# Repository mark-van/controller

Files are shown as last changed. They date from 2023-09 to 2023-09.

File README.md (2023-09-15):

# BLDC Controller

Designed a 300A 70V BLDC controller schematic to conform to relevant safety standards--UL2849, UL2272, and UL2271--and pass EMC certification tests 
- [Schematic PDF](/Project%20Outputs%20for%20Controller/schematics-2023-09-14.pdf) 

<br>

TODO:
- Add remaining safety protection circuits
- Clean up schematic
- Develop thorough documentation that describes the design’s protective circuitry and safety considerations so that it may act as a resource for future projects

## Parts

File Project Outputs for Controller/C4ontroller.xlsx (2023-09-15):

 | Bill of Materials
 |  |  |  |  |  |  | 2175 Salk Avenue
 | Project Title: | Bill of Materials for Project [Controller.PrjPcb] (No PCB Document Selected) |  |  |  |  | Suite 200
 | Project File Name: | Controller.PrjPcb |  |  |  |  | Carlsbad, CA 92008
 | Assembly Variant: | None |  |  |  |  | USA
Part Number | Description | Designator | Manufacture | Manufacture Part Number | Supplier | Supplier Part Number | Supplier Unit Price | Quantity
STM32F446RET6 | RISC Microcontroller, 32-Bit, FLASH, CORTEX-M4F CPU, 180MHz, CMOS, PQFP64 |  |  |  |  |  |  | 1
CGA3E1X7R1C105K080AC | CER 1UF 16V X7R 0603 | C1, C?, C?_U_Half_Bridge_1, C?_U_Half_Bridge_2, C?_U_Half_Bridge_3 |  |  |  |  |  | 14
GCM188R72A103KA37D | CER 10000PF 100V X7R 0603 | C2, C? |  |  |  |  |  | 4
GRT188C81E225KE13D | CER 2.2UF 25V X6S 0603 | C3, C4, C15 |  |  |  |  |  | 3
CGA3E2X7R1H104K080AA | CER 0.1UF 50V X7R 0603 | C5, C11, C12, C13, C14, C? |  |  |  |  |  | 6
GCM1885C2A100JA16D | CER 10PF 100V C0G/NP0 0603 | C6, C7 |  |  |  |  |  | 2
GCM1885C2A180JA16D | CER 18PF 100V C0G/NP0 0603 | C8, C9 |  |  |  |  |  | 2
GCM31CR71E475KA55L | CER 4.7UF 25V X7R 1206 | C10 |  |  |  |  |  | 1
12065A562JAT2A | CAP CER 5600PF 50V C0G/NP0 1206 | C? |  |  | DigiKey | 478-1501-1-ND |  | 1
EEV-FK1K471M | CAP ALUM 470UF 20% 80V SMD | C? |  |  |  |  |  | 6
GRM32EC80J107ME20L | CAP CER 100UF 6.3V X6S 1210 | C? |  |  |  |  |  | 2
GCJ188R72A104KA01D | CER 0.1UF 100V X7R 0603 | C? |  |  |  |  |  | 1
CGA3E2C0G1H472J080AA | CAP CER 4700PF 50V C0G 0603 | C? |  |  |  |  |  | 1
CAP 0402 |  | C? |  |  |  |  |  | 2
CAP 0402 |  | C? |  |  |  |  |  | 4
CAP 0402 |  | C? |  |  |  |  |  | 3
CAP 0603 |  | C? |  |  |  |  |  | 1
CAP 0603 |  | C? |  |  |  |  |  | 1
CAP 0402 |  | C? |  |  |  |  |  | 3
CGA3E1X5R0J475K080AC, CC0603JRNPO9BN510, C0603C104M3VAC7867, CGA3EAC0G2A103J080AC | CAP CER 4.7UF 6.3V X5R 0603, CAP CER 51PF 50V C0G/NPO 0603, CAP CER 0.1UF 25V Y5V 0603, CAP CER 10000PF 100V C0G 0603 | C?, C?_U_Half_Bridge_1, C?_U_Half_Bridge_2, C?_U_Half_Bridge_3 |  |  | DigiKey | 445-6934-1-ND, 311-3358-1-ND, 399-C0603C104M3VAC7867CT-ND, 445-16158-1-ND |  | 7
C0805C106K8PAC7800, 08053C104JAZ2A, C0805C564K5RAC7800 | CAP CER 10UF 10V X5R 0805, CAP CER 0.1UF 25V X7R 0805, CAP CER 0.56UF 50V X7R 0805 | C?, C?_U_Half_Bridge_1, C?_U_Half_Bridge_2, C?_U_Half_Bridge_3 |  |  | DigiKey | 399-C0805C106K8PAC7800CT-ND, 478-11877-1-ND, 399-C0805C564K5RAC7800CT-ND |  | 9
GCM155R71E273KA55D, GRM155R71H103KA88D, C1005X5R1V105K050BC, UMK105B7104KVHF, UMK105CBJ105MV-F, 885012005077, CBR04C330F2GAC, GCM1555C1H331JA16D, C0402C222J3GACAUTO | CAP CER 0.027UF 25V X7R 0402, CAP CER 10000PF 50V X7R 0402, CAP CER 1UF 35V X5R 0402, CAP CER 0.1UF 50V X7R 0402, CAP CER 1UF 50V X5R 0402, CAP CER 33PF 100V C0G/NP0 0402, CAP CER 33PF 200V C0G/NP0 0402, CAP CER 330PF 50V C0G/NP0 0402, CAP CER 2200PF 25V C0G/NP0 0402 | C?, C?_U_Half_Bridge_1, C?_U_Half_Bridge_2, C?_U_Half_Bridge_3, C?_U_Voltage_OpAmp1, C?_U_Voltage_OpAmp2, DO NOT PLACE_U_Half_Bridge_1, DO NOT PLACE_U_Half_Bridge_2, DO NOT PLACE_U_Half_Bridge_3 |  |  | DigiKey | 490-17757-1-ND, 490-4516-1-ND, 445-9073-1-ND, 587-4330-1-ND, 587-6278-1-ND, 732-12070-1-ND, 399-16337-1-ND, 490-4928-1-ND, 399-C0402C222J3GACAUTOCT-ND |  | 45
GCJ32DR72A225KA01L | CER 2.2UF 100V X7R 1210 | C?_U_Half_Bridge_1, C?_U_Half_Bridge_2, C?_U_Half_Bridge_3, Cin |  |  |  |  |  | 4
CL31B106KAHVPNE | CER 10UF 25V X7R 1206 | C?_U_Half_Bridge_1, C?_U_Half_Bridge_2, C?_U_Half_Bridge_3, Cout |  |  |  |  |  | 10
C0805C470K5GACAUTO | CER 47PF 50V C0G/NP0 0805 | Cac |  |  |  |  |  | 1
B04B-XASK-1(LF)(SN) | CONN HEADER VERT 4POS 2.5MM | CAN, I2C Bus |  |  | DigiKey | 455-1994-ND |  | 2
CL21B222KB6WPNC | CER 2200PF 50V X7R 0805 | Cbst |  |  |  |  |  | 1
GCM155R71H122KA37D | CER 1200PF 50V X7R 0402 | Cr |  |  |  |  |  | 1
MMSZ5238BT1G | DIODE ZENER 8.7V 500MW SOD123 | D? |  |  | DigiKey | MMSZ5238BT1GOSCT-ND |  | 1
CMS06(TE12L,Q,M) | DIODE SCHOTTKY 30V 2A M-FLAT | D? |  |  |  |  |  | 1
DSILC6-4P6 | TVS DIODE 5VWM SOT666 | D? |  |  |  |  |  | 1
PESD1CAN,215 | Trans Voltage Suppressor Diode, 200W, 24V V(RWM), Bidirectional, 2 Element, Silicon, TO-236AB | D? |  |  |  |  |  | 1
ER1J-LTP | DIODE GEN PURP 600V 1A DO214AA | D?_U_Half_Bridge_1, D?_U_Half_Bridge_2, D?_U_Half_Bridge_3 |  |  | DigiKey | ER1J-LTPMSCT-ND |  | 12
RES 0603 |  | DO NOT PLACE_U_Half_Bridge_1, DO NOT PLACE_U_Half_Bridge_2, DO NOT PLACE_U_Half_Bridge_3, R? |  |  |  |  |  | 11
BM08B-SRSS-TB(LF)(SN) | CONN HEADER SMD 8POS 1MM | Extra Power, USART |  |  | DigiKey | 455-1794-1-ND |  | 2
LTST-C191KGKT | LED GREEN CLEAR SMD | GLED? |  |  |  |  |  | 3
B6B-PH-K-S(LF)(SN) | CONN HEADER VERT 6POS 2MM | HALL |  |  |  |  |  | 1
DM3CS-SF | CONN MICRO SD CARD HINGED TYPE | J? |  |  | DigiKey | HR1972TR-ND |  | 1
B7B-XH-A(LF)(SN) | CONN HEADER VERT 7POS 2.5MM | J? |  |  | DigiKey | 455-2252-ND |  | 1
302-S201 | CONN HEADER VERT 20POS 2.54MM | J? |  |  | DigiKey | ED10524-ND |  | 1
FTSH-105-01-L-DV-007-K | CONN HEADER SMD 10POS 1.27MM | J? |  |  |  |  |  | 1
J100A | Connector pad, 110 A | J? |  |  |  |  |  | 1
J100A | Connector pad, 110 A | J? |  |  |  |  |  | 1
J100A | Connector pad, 110 A | J? |  |  |  |  |  | 1
FTSH-105-01-L-DV-007-K | CONN HEADER SMD 10POS 1.27MM | J? |  |  |  |  |  | 1
J100A | Connector pad, 110 A | J? |  |  |  |  |  | 1
J100A | Connector pad, 110 A | J? |  |  |  |  |  | 1
J100A | Connector pad, 110 A | J? |  |  |  |  |  | 1
J100A | Connector pad, 110 A | J? |  |  |  |  |  | 1
J100A | Connector pad, 110 A | J? |  |  |  |  |  | 1
J100A | Connector pad, 110 A | J? |  |  |  |  |  | 1
RK73Z1JTTD | RES 0 OHM JUMPER 0603 | J?, J?_U_Half_Bridge_1, J?_U_Half_Bridge_2, J?_U_Half_Bridge_3, R2, R3, R4, R5, R? |  |  |  |  |  | 12
MSS1210-683MED | 68uH Shld 20% 4.3A 84mOhms AECQ2 | L1 |  |  |  |  |  | 1
B82789C0104N002 | CMC 100UH 150MA 2LN SMD AEC-Q200 | L? |  |  |  |  |  | 1
MHQ0402PSA3N9BT000 | FIXED IND 3.9NH 200MA 750MOHM SM | L? |  |  |  |  |  | 1
MLZ1608N100LTD25 | FIXED IND 10UH 300MA 600MOHM SMD | L? |  |  |  |  |  | 1
744786115A | FIXED IND 15NH 500MA 500MOHM SMD | L? |  |  |  |  |  | 1
B02B-XASK-1(LF)(SN) | CONN HEADER VERT 2POS 2.5MM | NFC |  |  | DigiKey | 455-1989-ND |  | 1
FDBL86210-F085 | N-CH 150V 169A 8HPSOF | Q?_U_Half_Bridge_1, Q?_U_Half_Bridge_2, Q?_U_Half_Bridge_3 |  |  |  |  |  | 18
EXB-28V563JX | RES ARRAY 4 RES 56K OHM 0804 | R? |  |  | DigiKey | Y7563CT-ND |  | 2
RK73H1JTTD4701F, ERJ-3EKF1330V | RES 4.7K OHM 1% 1/10W 0603, RES SMD 133 OHM 1% 1/10W 0603 | R? |  |  | DigiKey | 2019-RK73H1JTTD4701FCT-ND, P133HCT-ND |  | 5
CRCW08051K54FKEA | RES SMD 1.54K OHM 1% 1/8W 0805 | R? |  |  | DigiKey | 541-1.54KCCT-ND |  | 1
ERJ-P08J620V, RC1206FR-1011KL | RES SMD 62 OHM 5% 2/3W 1206, RES 11K OHM 1% 1/4W 1206 | R? |  |  | DigiKey | P62ALCT-ND, 13-RC1206FR-1011KLCT-ND |  | 3
RMCF0603FT100K | RES 100K OHM 1% 1/10W 0603 | R? |  |  |  |  |  | 1
AC0402FR-0710KL | RES SMD 10K OHM 1% 1/16W 0402 | R? |  |  |  |  |  | 2
RMCF0603FT10K0 | RES 10K OHM 1% 1/10W 0603 | R?, R?_U_Half_Bridge_1, R?_U_Half_Bridge_2, R?_U_Half_Bridge_3 |  |  |  |  |  | 7
AC0402JR-07100KL, RC0402FR-0768K1L, ERJ-2RKF1333X, CRCW040219K1FKEDC, CRCW04022K00FKED, RMCF0402FT10R0, TNPW040251K1BEED, RMCF0402FT1M00, RMCF0402FT51R0, ERA-2AEB332X, ERA-2AEB4021X | RES SMD 100K OHM 5% 1/16W 0402, RES 68.1K OHM 1% 1/16W 0402, RES SMD 133K OHM 1% 1/10W 0402, RES 19.1K OHM 1% 1/16W 0402, RES SMD 2K OHM 1% 1/16W 0402, RES 10 OHM 1% 1/16W 0402, RES 51.1K OHM 0.1% 1/16W 0402, RES 1M OHM 1% 1/16W 0402, RES 51 OHM 1% 1/16W 0402, RES SMD 3.3K OHM 0.1% 1/16W 0402, RES SMD 4.02KOHM 0.1% 1/16W 0402 | R?, R?_U_Half_Bridge_1, R?_U_Half_Bridge_2, R?_U_Half_Bridge_3, R?_U_Voltage_OpAmp1, R?_U_Voltage_OpAmp2 |  |  | DigiKey | YAG3515CT-ND, YAG3213CT-ND, P133KLCT-ND, 541-4765-1-ND, 541-2.00KLCT-ND, RMCF0402FT10R0CT-ND, TNP51.1KDACT-ND, RMCF0402FT1M00CT-ND, RMCF0402FT51R0CT-ND, P3.3KDCCT-ND, P4.02KDCCT-ND |  | 53
PSL2NTEBL500F | RES 500 UOHM 1% 8W NONSTANDARD | R?_U_Half_Bridge_1, R?_U_Half_Bridge_2, R?_U_Half_Bridge_3 |  |  |  |  |  | 9
MMB02070C1208FB200 | RES SMD 1.2 OHM 1% 1W 0207 | R?_U_Half_Bridge_1, R?_U_Half_Bridge_2, R?_U_Half_Bridge_3 |  |  |  |  |  | 18
RMCF0603FT49K9 | RES 49.9K OHM 1% 1/10W 0603, Thick Film | Rfbb |  |  |  |  |  | 1
RMCF0603FT453K | RES 453K OHM 1% 1/10W 0603, Thick Film | Rfbt |  |  |  |  |  | 1
CRCW0805100KFKEA | RES SMD 100K OHM 1% 1/8W 0805, Thick Film | Ron |  |  |  |  |  | 1
ERJ-6ENF2373V | RES SMD 237K OHM 1% 1/8W 0805, Thick Film | Rr |  |  |  |  |  | 1
KXT341 LHS | SWITCH TACTILE SPST-NO 0.02A 15V | S? |  |  | DigiKey | CKN10781CT-ND |  | 3
OS102011MS2QN1C | SLIDE SWITCH SPDT T/H ON-ON BBM | S? |  |  |  |  |  | 2
DRQ125-150-R | INDUCT ARRAY 2 COIL 15.35UH SMD | T? |  |  |  |  |  | 1
5002 | PC TEST POINT MINIATURE WHITE | TP? |  |  |  |  |  | 7
5011 | PC TEST POINT MULTIPURPOSE BLACK | TP? |  |  |  |  |  | 4
LM5164QDDARQ1 | Buck Switching Regulator IC Positive Adjustable 1.2V 1 Output 1A 8-PowerSOIC (0.154", 3.90mm Width) | U1 |  |  |  |  |  | 1
LM5160DNTR | IC REG BUCK FLYBCK ADJ 12WSON | U? |  |  |  |  |  | 1
NRF52832-QFAA-R | IC RF TXRX+MCU BLUETOOTH 48VFQFN | U? |  |  |  |  |  | 1
SN65HVD232DR | IC TRANSCEIVER HALF 1/1 8SOIC | U? |  |  |  |  |  | 1
MCP9808T-E/MC | Temperature Sensor Digital, Local -40°C ~ 125°C 12 b 8-DFN (2x3) | U? |  |  |  |  |  | 8
UCC21521DWR | DGTL ISO 5.7KV GATE DRVR 16SOIC | U?_U_Half_Bridge_1, U?_U_Half_Bridge_2, U?_U_Half_Bridge_3 |  |  |  |  |  | 3
AMC1302QDWVRQ1 | IC CURRENT ISOLATION 8SOIC | U?_U_Half_Bridge_1, U?_U_Half_Bridge_2, U?_U_Half_Bridge_3 |  |  |  |  |  | 3
AMC1311BQDWVRQ1 | Isolation Amplifier, 1 Func, 2121V Isolation-Min, 280MHz Band Width, PDSO8 | U?_U_Half_Bridge_1, U?_U_Half_Bridge_2, U?_U_Half_Bridge_3 |  |  |  |  |  | 3
TLV9004QDRQ1 | IC OPAMP GP 4 CIRCUIT 14SOIC | U?_U_Voltage_OpAmp1, U?_U_Voltage_OpAmp2 |  |  |  |  |  | 2
10118193-0001LF | FCI Right Angle Surface Mount Mount Female USB Connector; 100 V ac; 1.8A | USB |  |  |  |  |  | 1
NX3215SA-32.768K-STD-MUS-2 | 32.7680KHZ 12.5PF SMD | X2 |  |  |  |  |  | 1
ECS-320-8-37CKM | CRYSTAL 32.0000MHZ 8PF SMD | X? |  |  |  |  |  | 1
CX3225SB48000D0FPJC1 | CRYSTAL 48.0000MHZ 8PF SMD | X? |  |  |  |  |  | 1
ECS-.327-9-34QCS-TR | CRYSTAL 32.768KHZ 9PF SMD | X? |  |  |  |  |  | 1
 |  |  |  |  |  |  | $0.00 | 371
Approved |  | Notes

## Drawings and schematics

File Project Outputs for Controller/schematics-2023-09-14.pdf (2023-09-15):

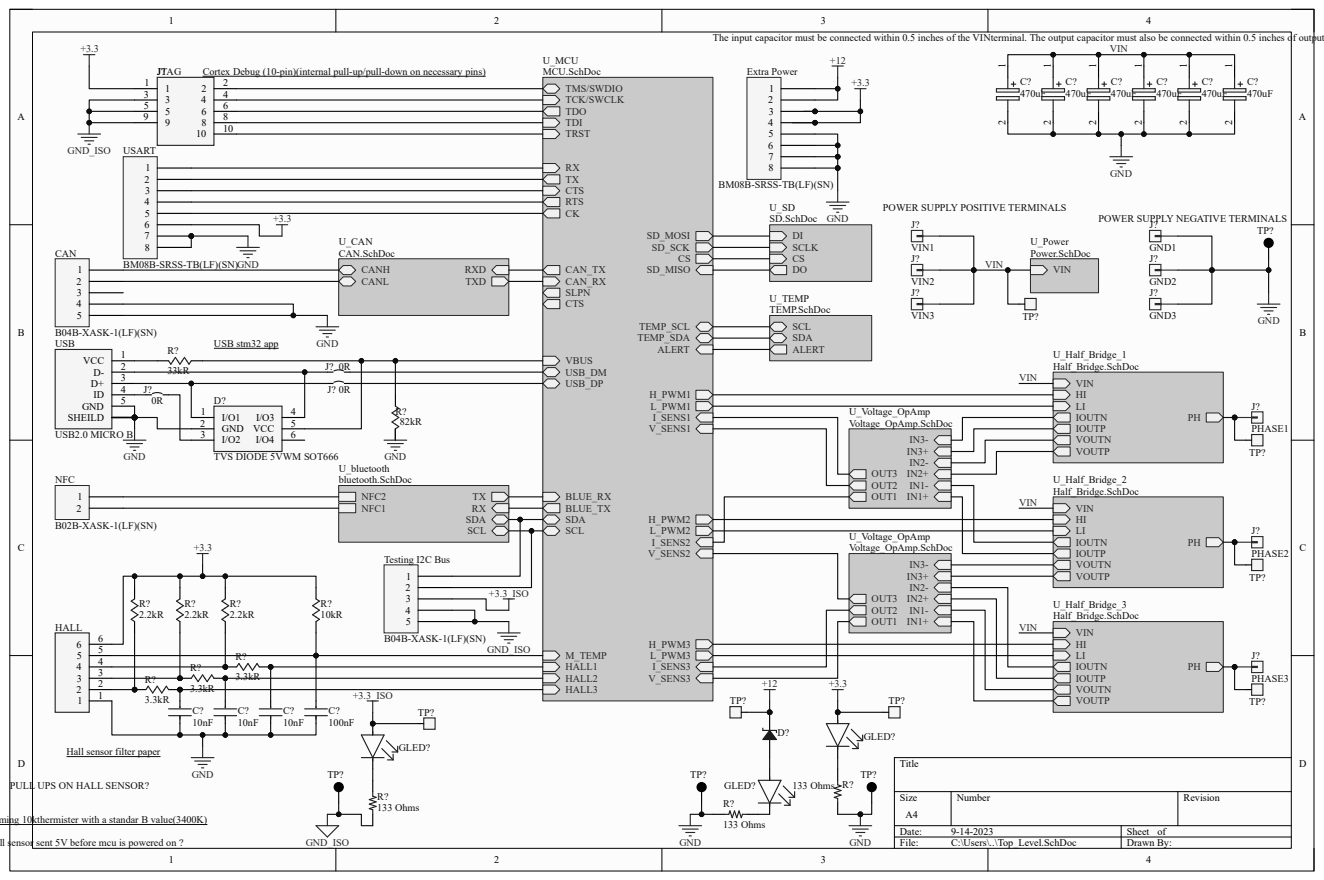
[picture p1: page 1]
Title; Size; Number; Revision; Date:; Sheet of; File:; C:\Users\..\Top_Level.SchDoc; Drawn By:; VIN HI LI; VOUTP; VOUTN; IOUTP; IOUTN; U_Half_Bridge_1 Half_Bridge.SchDoc; VIN; U_Power Power.SchDoc; I_SENS1; I_SENS2; I_SENS3; V_SENS1; V_SENS3; V_SENS2; L_PWM1; L_PWM2; H_PWM1; H_PWM2; H_PWM3; HALL1 HALL2 HALL3; M_TEMP; TRST; TDO; TMS/SWDIO TCK/SWCLK; TDI; VBUS USB_DM USB_DP; L_PWM3; TEMP_SCL TEMP_SDA; CAN_RX; CAN_TX; CTS; SLPN; ALERT; CTS RTS CK; SD_SCK; SD_MISO; SD_MOSI; BLUE_RX BLUE_TX SDA SCL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

The input capacitor must be connected within 0.5 inches of the VINterminal. The output capacitor must also be connected within 0.5 inches of output pinText

BM08B-SRSS-TB(LF)(SN)

POWER SUPPLY POSITIVE TERMINALS

POWER SUPPLY NEGATIVE TERMINALS

Hall sensor filter paper

PULL UPS ON HALL SENSOR?

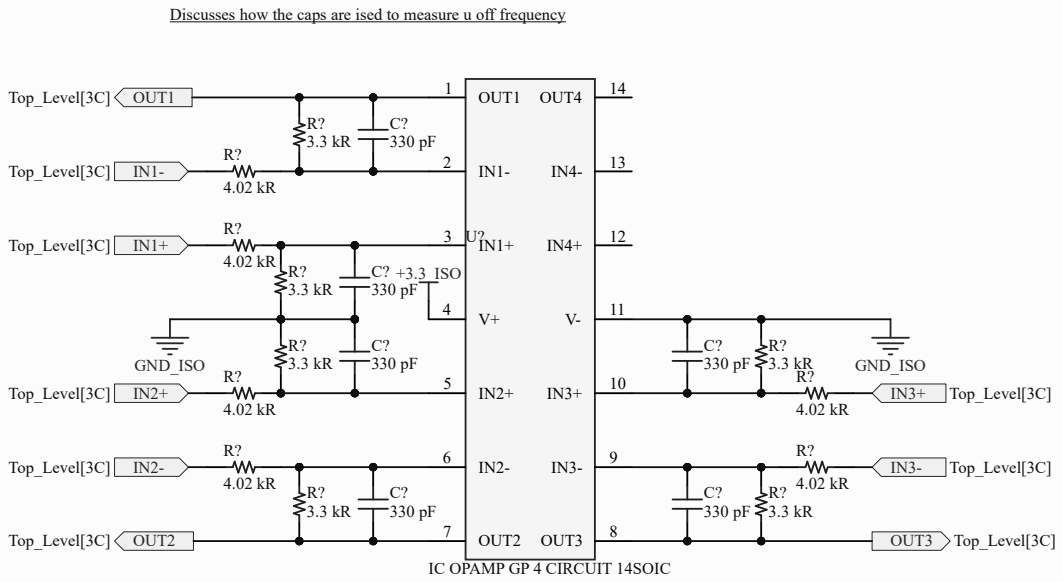
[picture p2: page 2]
Title; Size; Number; Revision; File:; C:\Users\..\Voltage_OpAmp.SchDoc; Drawn By:; OUT1 1; OUT2 7; OUT4; OUT3; Top_Level[3C]; OUT1; GND_ISO; +3.3_ISO; OUT2; OUT3 Top_Level[3C]

Discusses how the caps are ised to measure u off frequency

IC OPAMP GP 4 CIRCUIT 14SOIC

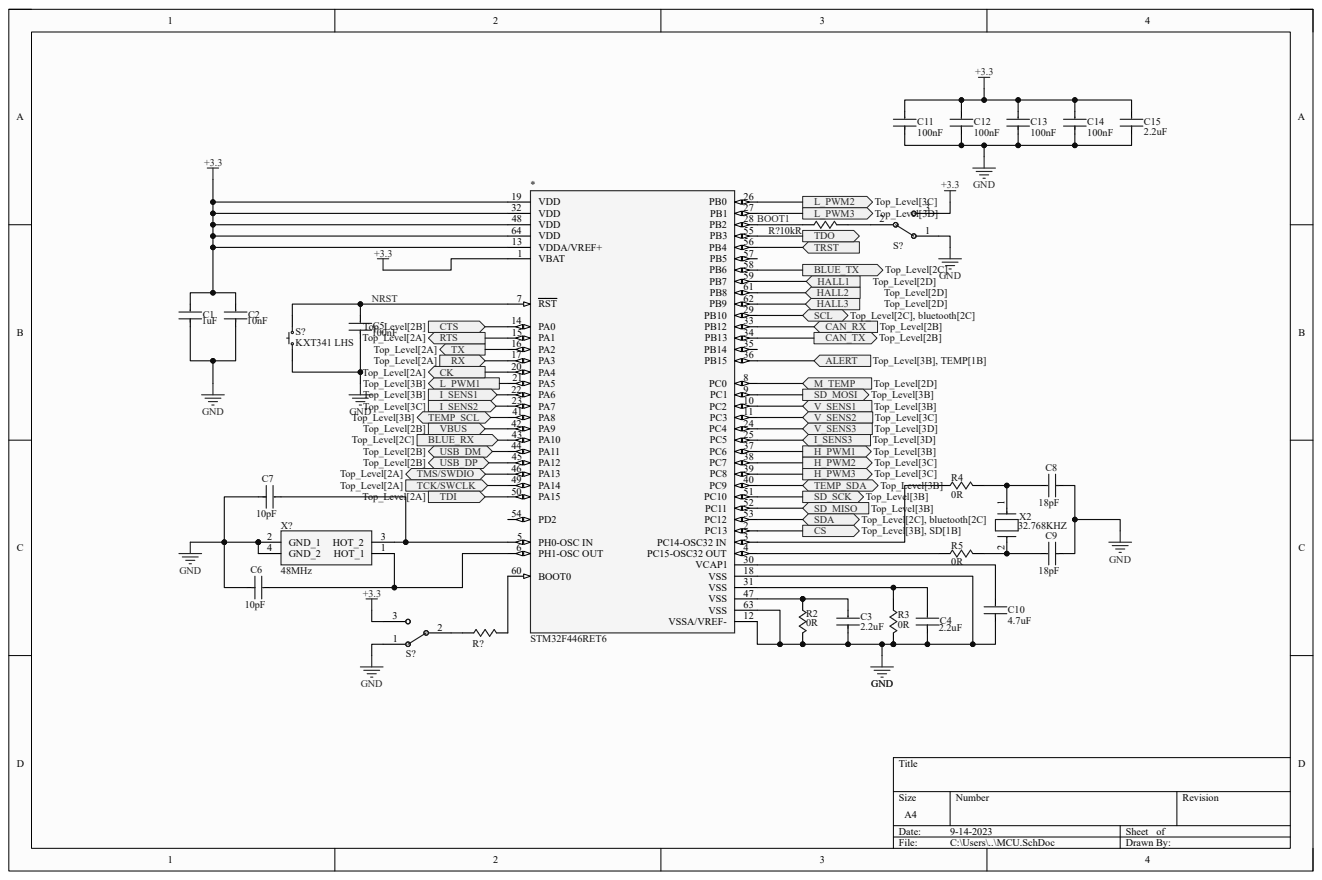
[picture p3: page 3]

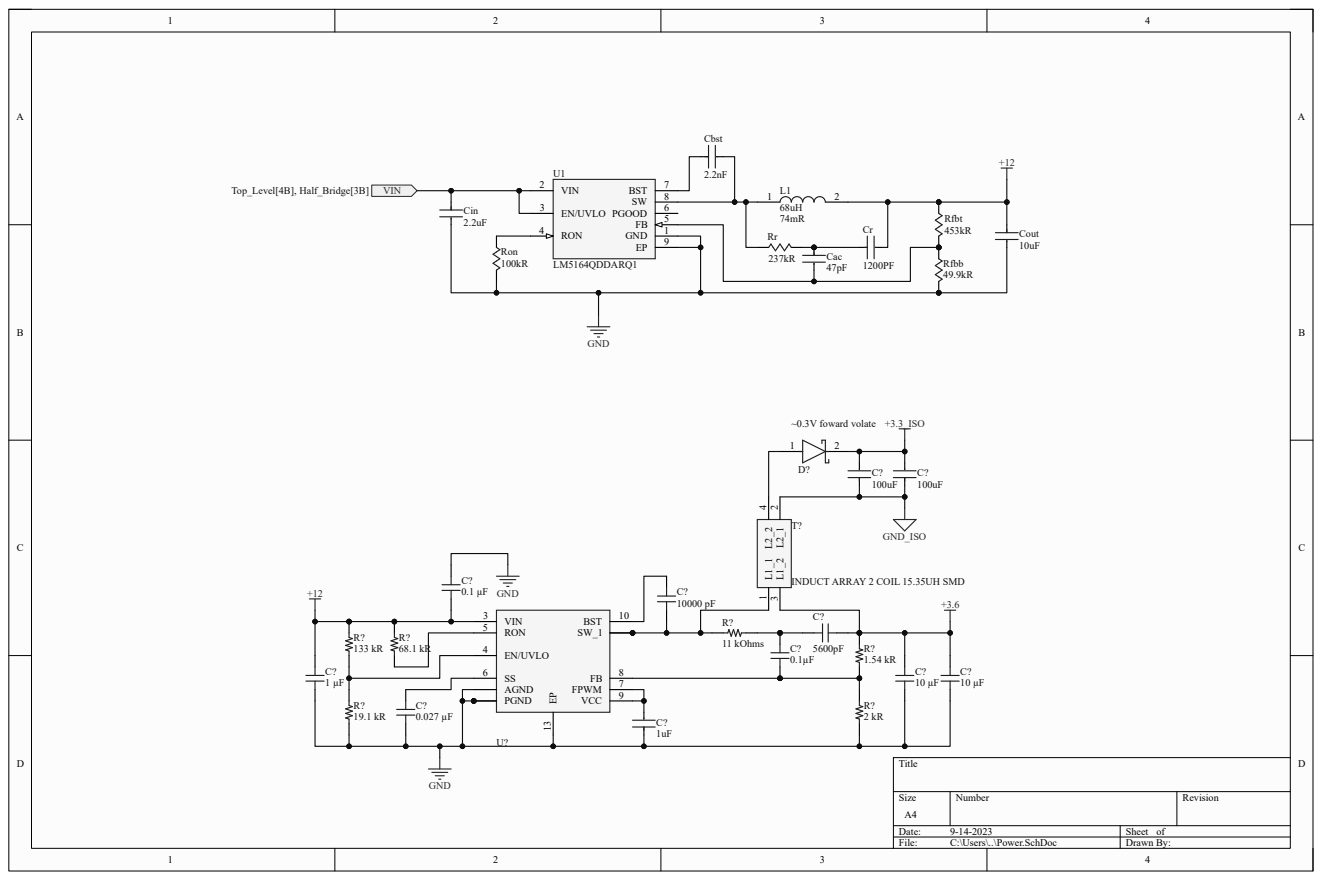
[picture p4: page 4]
Title; Size; Number; Revision; File:; C:\Users\..\Power.SchDoc; Drawn By:; EN/UVLO 3; RON 4; VIN 2; BST; GND; PGOOD; LM5164QDDARQ1; Cout 453kR; Rfbt; Rfbb; Ron; Cbst; Cin; Cac; Top_Level[4B], Half_Bridge[3B]; VIN; AGND; VIN 3; EN/UVLO 4; RON 5; VCC; FPWM; PGND; +3.3_ISO; GND_ISO; ~0.3V foward volate; 11 kOhms

INDUCT ARRAY 2 COIL 15.35UH SMD

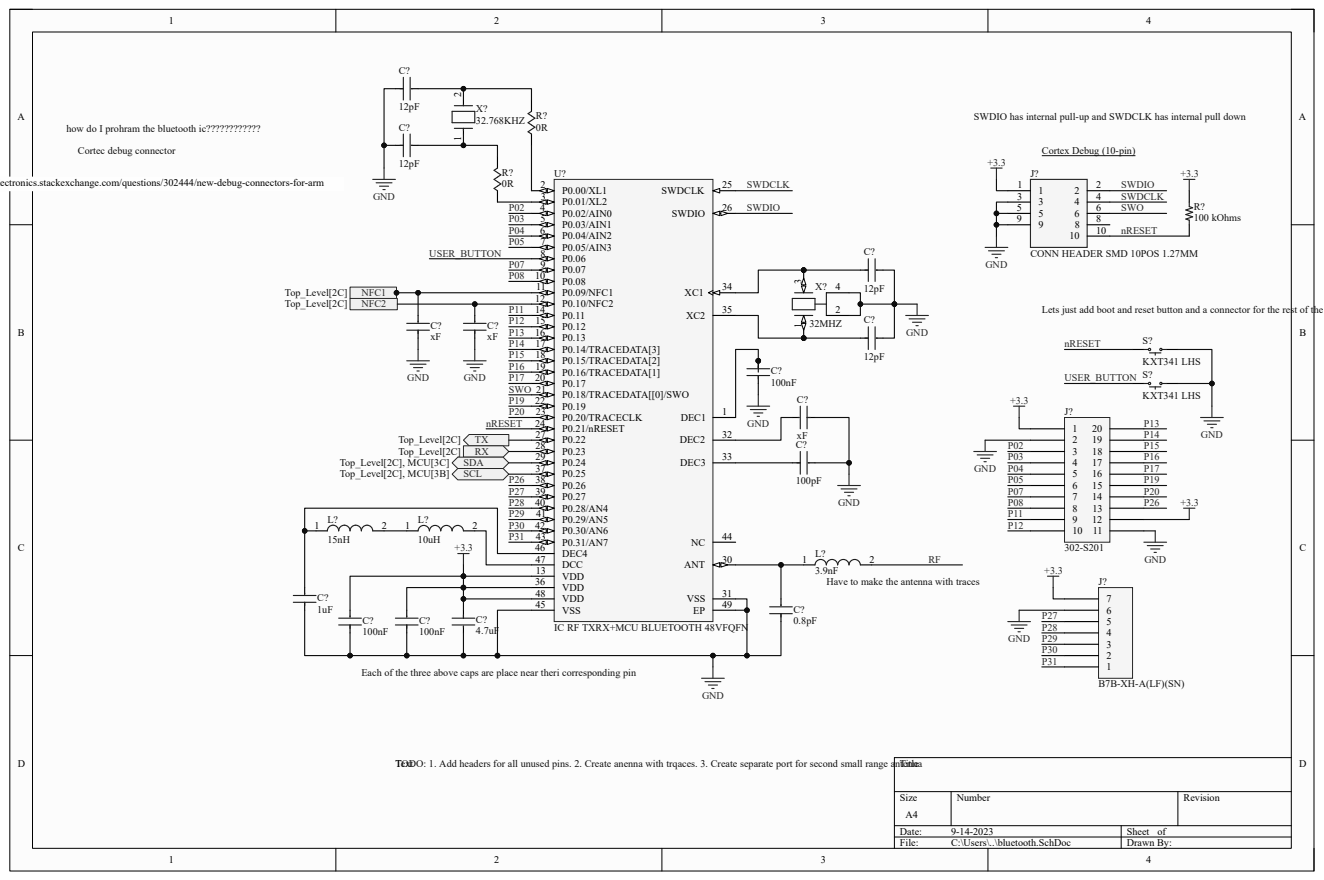
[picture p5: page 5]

SWDIO has internal pull-up and SWDCLK has internal pull down

how do I prohram the bluetooth ic????????????

https://electronics.stackexchange.com/questions/302444/new-debug-connectors-for-arm

Lets just add boot and reset button and a connector for the rest of the pins+extra gnd power pins

IC RF TXRX+MCU BLUETOOTH 48VFQFN

Each of the three above caps are place near theri corresponding pin

TextODO: 1. Add headers for all unused pins. 2. Create anenna with trqaces. 3. Create separate port for second small range antenna

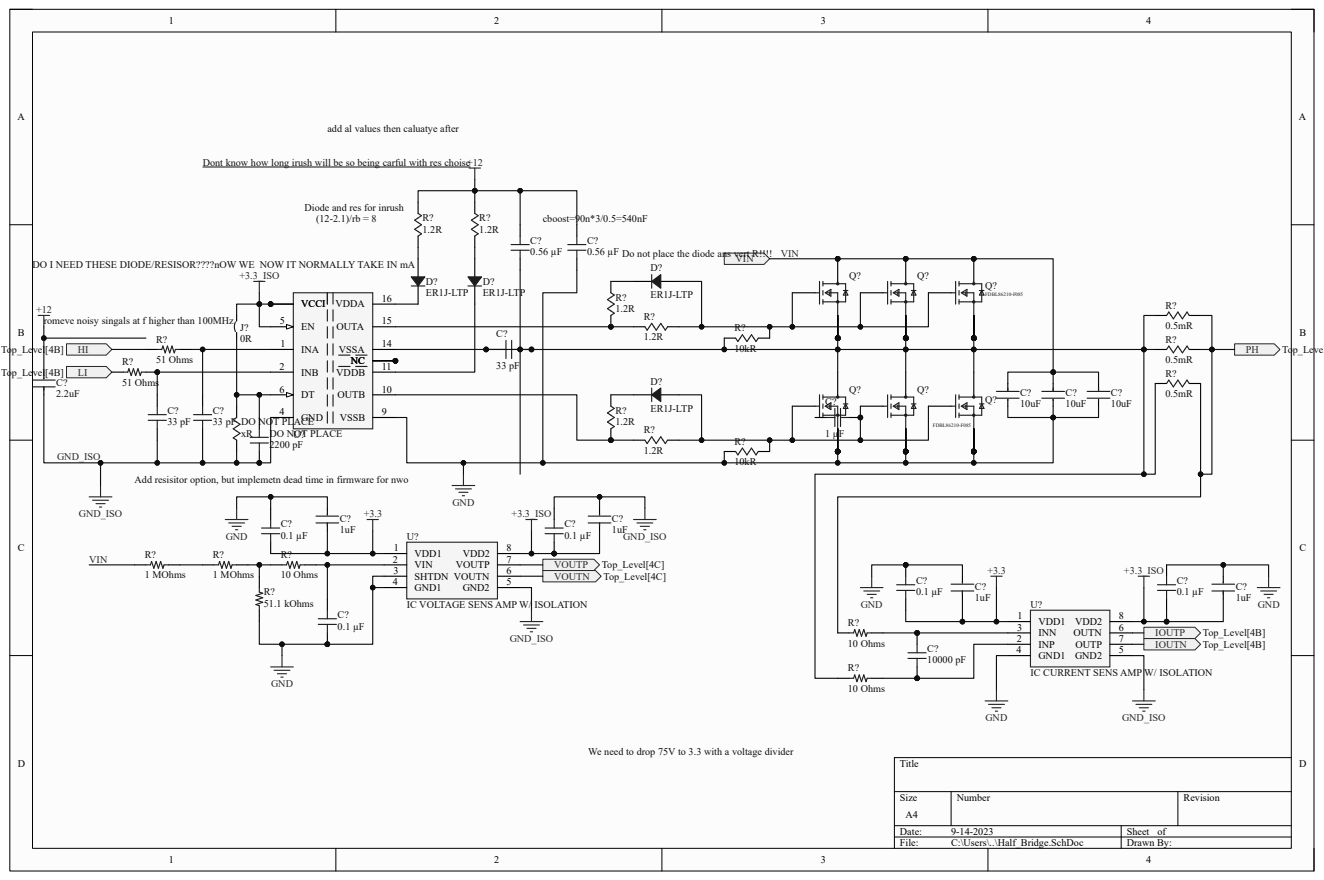
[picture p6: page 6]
Title; Size; Number; Revision; File:; C:\Users\..\Half_Bridge.SchDoc; Drawn By:; VIN; FDBL86210-F085; Top_Level[4B]; GND_ISO; VCCI; VDDA; VDDB; INA 1; INB 2; OUTA; OUTB; GND 4; VSSA; VSSB; GND; +3.3_ISO; ER1J-LTP; D? ER1J-LTP; cboost=90n*3/0.5=540nF; 51 Ohms; VDD1 1; VDD2; INN 3 INP 2; OUTN; OUTP; GND1 4; GND2; VDD1 1 VIN 2 SHTDN 3 GND1 4; VOUTP; VOUTN; 1 MOhms; 51.1 kOhms; 10 Ohms; Top_Level[4C]; C? GND 1uF; IOUTP; IOUTN

add al values then caluatye after

Dont know how long irush will be so being carful with res choise

Diode and res for inrush

Do not place the diode ans vert R!!!!

DO I NEED THESE DIODE/RESISOR????nOW WE NOW IT NORMALLY TAKE IN mA

romeve noisy singals at f higher than 100MHz

DO NOT PLACE

Add resisitor option, but implemetn dead time in firmware for nwo

IC VOLTAGE SENS AMP W/ ISOLATION

IC CURRENT SENS AMP W/ ISOLATION

We need to drop 75V to 3.3 with a voltage divider

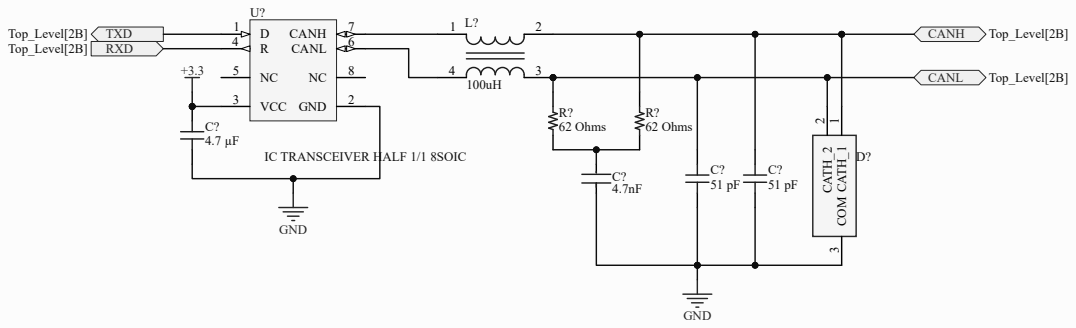
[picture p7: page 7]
Title; Size; Number; Revision; File:; C:\Users\..\CAN.SchDoc; Drawn By:; R? 62 Ohms; CATH_1; 1 CATH_2; 2 COM; GND; CANH; Top_Level[2B]; CANL; TXD; RXD; 2 VCC 3

IC TRANSCEIVER HALF 1/1 8SOIC

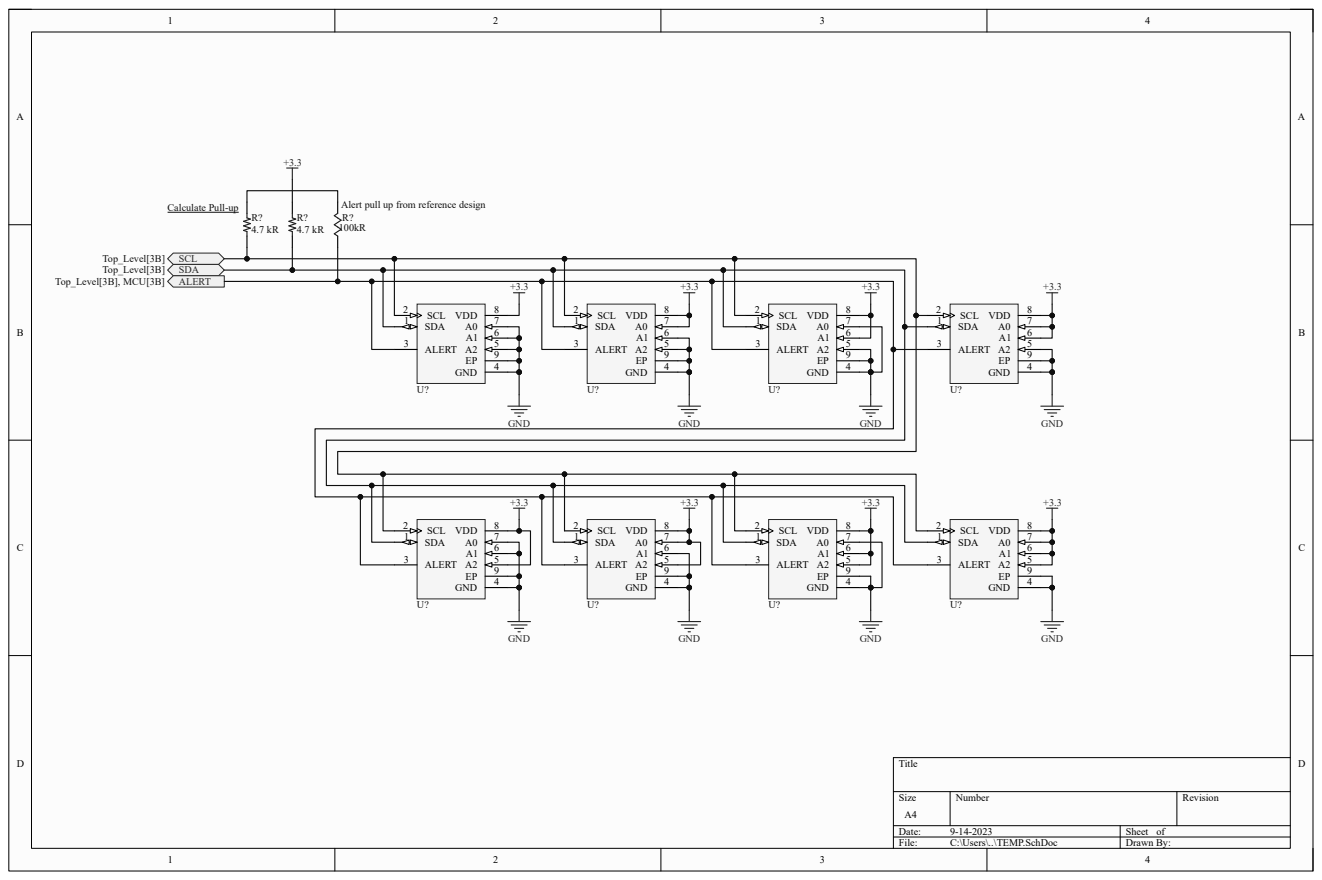
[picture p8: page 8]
Title; Size; Number; Revision; File:; C:\Users\..\TEMP.SchDoc; Drawn By:; SDA 1; SCL 2; ALERT 3; GND; VDD; Top_Level[3B]; SCL; SDA; Top_Level[3B], MCU[3B]; ALERT; Calculate Pull-up; Alert pull up from reference design

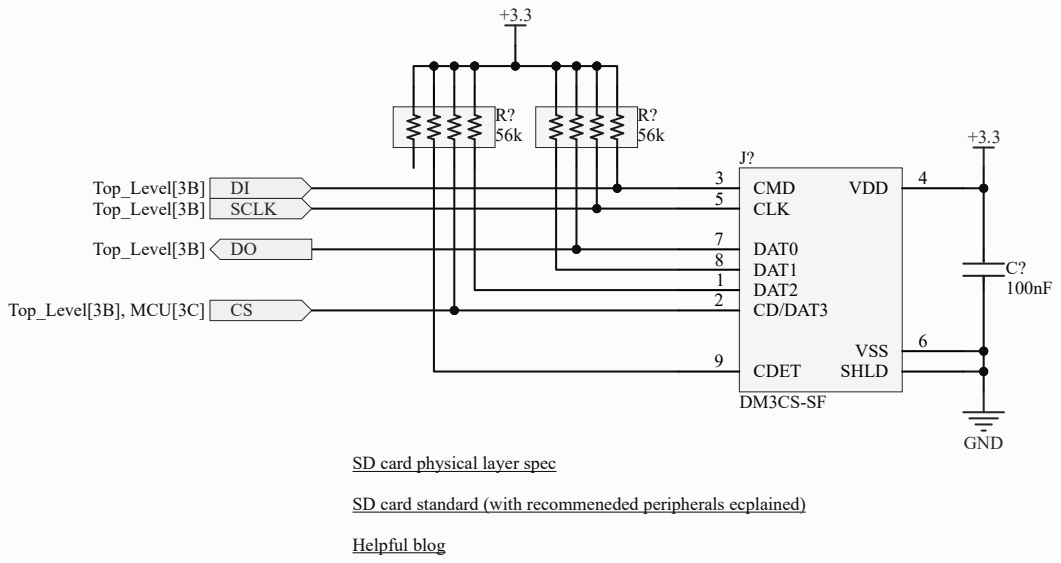
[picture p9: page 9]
Title; Size; Number; Revision; File:; C:\Users\..\SD.SchDoc; Drawn By:; DAT2 1 CD/DAT3 2; CMD 3; VDD; CLK 5; VSS; DAT0 7 DAT1 8; CDET 9; SHLD; GND; Top_Level[3B]; SCLK; Top_Level[3B], MCU[3C]; Helpful blog

SD card physical layer spec

SD card standard (with recommeneded peripherals ecplained)

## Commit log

2023-05-24 finished power schem
    [MCU.SchDoc, Power.SchDoc, Schlib2.SchLib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]
2023-05-25 70% half bridge
    [Controller.PrjPcb, Half_Bridge.SchDoc, MCU.SchDoc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]
2023-05-27 still need to add connectors and complete top level sheet
    [Controller.PrjPcb, Half_Bridge.SchDoc, MCU.SchDoc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]
2023-05-27 all thats left is adding connectors
    [Top_Level.SchDoc]
2023-05-28 nearly done schematic
    [MCU.SchDoc, PcbLib2.PcbLib, Schlib2.SchLib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]
2023-05-29 about to make adc changes
    [MCU.SchDoc, Schlib2.SchLib, Top_Level.SchDoc]
2023-05-29 started adding second motor
    [MCU.SchDoc, PcbLib2.PcbLib, Schlib2.SchLib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]
2023-06-04 reverting to one motor, adding can
    [CAN.SchDoc, Controller.PrjPcb, MCU.SchDoc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]
2023-06-05 updated mcu
    [CAN.SchDoc, MCU.SchDoc, PcbLib2.PcbLib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]
2023-06-05 starting on temp and sd schem
    [CAN.SchDoc, Controller.PrjPcb, Half_Bridge.SchDoc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]
2023-06-06 added temp and sd schem
    [SD.SchDoc, Schlib2.SchLib, TEMP.SchDoc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]
2023-06-07 connecred sheets at toplevel
    [MCU.SchDoc, Top_Level.SchDoc, bluetooth.SchDoc]
2023-06-09 added bluetooth connectors and buttons
    [PcbLib2.PcbLib, Schlib2.SchLib, Top_Level.SchDoc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]
2023-06-10 non-iso schem complete
    [Top_Level.SchDoc, bluetooth.SchDoc]
2023-06-12 started adding iso
    [Schlib2.SchLib, Top_Level.SchDoc]
2023-06-15 changing dc iso to 3.6
    [Half_Bridge.SchDoc, Power.SchDoc, Schlib2.SchLib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]
2023-06-15 completed 3.3 dc iso
    [Power.SchDoc, Schlib2.SchLib]
2023-06-16 started adding iso amps
    [Half_Bridge.SchDoc, Power.SchDoc, Schlib2.SchLib]
2023-06-20 began populating votl iso amp
    [Half_Bridge.SchDoc, Schlib2.SchLib, Top_Level.SchDoc]
2023-06-27 finished adding iso-amps
    [Controller.PrjPcb, Half_Bridge.SchDoc, Schlib2.SchLib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]
2023-09-15 added ~1/4 of safety circuitry
    [C3ontroller.xls, C4ontroller.xlsx, C5ontroller.xlsx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]
